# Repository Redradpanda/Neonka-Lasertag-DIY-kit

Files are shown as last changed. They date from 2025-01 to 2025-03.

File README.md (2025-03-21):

# Neonka-Lasertag-DIY-kit
Das ist ein Open Source Lasertag Projekt zum selber nachbauen.

lasertag front image

Alle notwendige Dateien und eine Anleitung sind in diesem Projekt gespeichert.

Dieses Hardware-Design ist lizenziert unter "CERN Open Hardware Licence Strongly Reciprocal, Version 2.0."
Den vollständigen Lizenztext finden Sie in der LICENSE-Datei.

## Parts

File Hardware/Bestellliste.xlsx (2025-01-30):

Bauteilkosten Lasertag
 | Pistole
 | Bauteil | Beschreibung | Link/Bestelladresse | CHF pro Stk. | Anzahl | CHF Total
 | Batteriehalter | 18650 Batteriehalter | https://de.aliexpress.com/item/1005006283753220.html | 1.03 | 1 | 1.03
 | Li-ion Batterien | 18650 Batterie (mit Schutzschaltung) |  | 9.9 | 1 | 9.9
 | ESP-32 | FireBeetle 2 ESP32-E |  | 12.9 | 1 | 12.9
 | Buzzer | 3V Piezo passiv Buzzer | https://www.mouser.ch/ProductDetail/Same-Sky/CMI-0955-03TH?qs=olJun0bQHM8qnyh30s0SwQ%3D%3D | 0.71 | 1 | 0.71
 | Sprungfeder | L2, R2 Steam Deck ersatzfeder | https://de.aliexpress.com/item/1005006748194855.html | 0.74 | 1 | 0.74
 | Linse | Bikonvex Linse (Google Cardboard), 25mm Brennweite 45mm fokalpunkt | https://de.aliexpress.com/item/1005006960995428.html | 0.29 | 1 | 0.29
 | Infrarot-LED | WP7113SF4BT-P22 | https://www.mouser.ch/ProductDetail/Kingbright/WP7113SF4BT-P22?qs=fAHHVMwC%252BbiHZc2nn9bMjA%3D%3D | 0.65 | 1 | 0.65
 | Kondensator | 100nF THT (ceramic) |  | 0.5 | 1 | 0.5
 | Widerstand | 47 Ohm THT |  | 0.01 | 1 | 0.01
 | Widerstand | 100 Ohm THT |  | 0.01 | 1 | 0.01
 | Widerstand | 10k Ohm THT |  | 0.01 | 2 | 0.02
 | Taster |  | https://de.aliexpress.com/item/1005004254514071.html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 | 0.05 | 1 | 0.05
 | Transistor | BS-170 THT |  | 0.05 | 1 | 0.05
 |  |  |  |  | Zwischentotal: | 26.86
 | Hit Detektor
 | Batteriehalter | 18650 Batteriehalter | https://de.aliexpress.com/item/1005006283753220.html | 1.03 | 1 | 1.03
 | Li-ion Batterien | 18650 Batterie (mit Schutzschaltung) |  | 9.9 | 1 | 9.9
 | ESP-32 | FireBeetle 2 ESP32-E |  | 12.9 | 1 | 12.9
 | Buzzer | 3V Piezo passiv Buzzer |  | 0.71 | 1 | 0.71
 | Infrarot-Reciever | TSOP-4138 | https://www.mouser.ch/ProductDetail/Vishay-Semiconductors/TSOP4138?qs=%2FCr5RXwmPBOIXjZmt6OK%2Fg%3D%3D | 0.6 | 6 | 3.6
 |  |  |  |  | Zwischentotal: | 28.14
 |  |  |  | Total: |  | 55

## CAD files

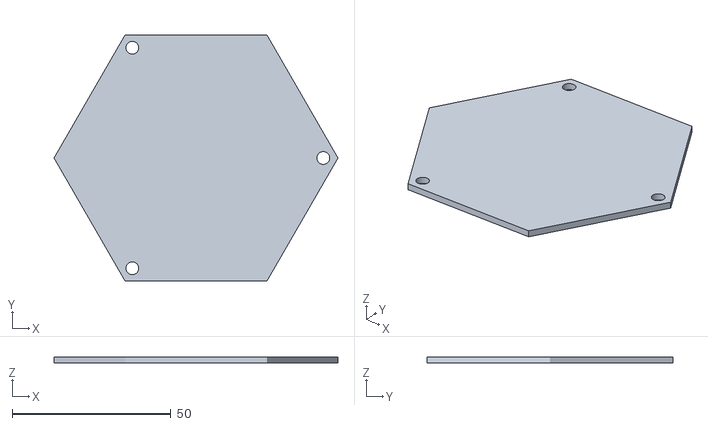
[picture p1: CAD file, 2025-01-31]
Mechanik/Hit Detektor/H-Deckel.stl
89.4 x 77.4 x 2.00

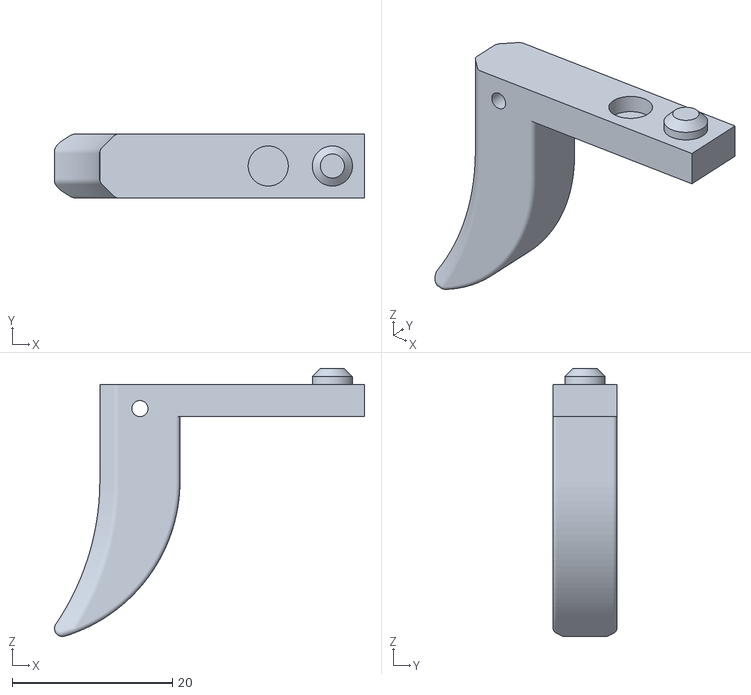
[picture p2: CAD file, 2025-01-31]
Mechanik/Pistole/P-Trigger.stl
38.7 x 8.00 x 33.4

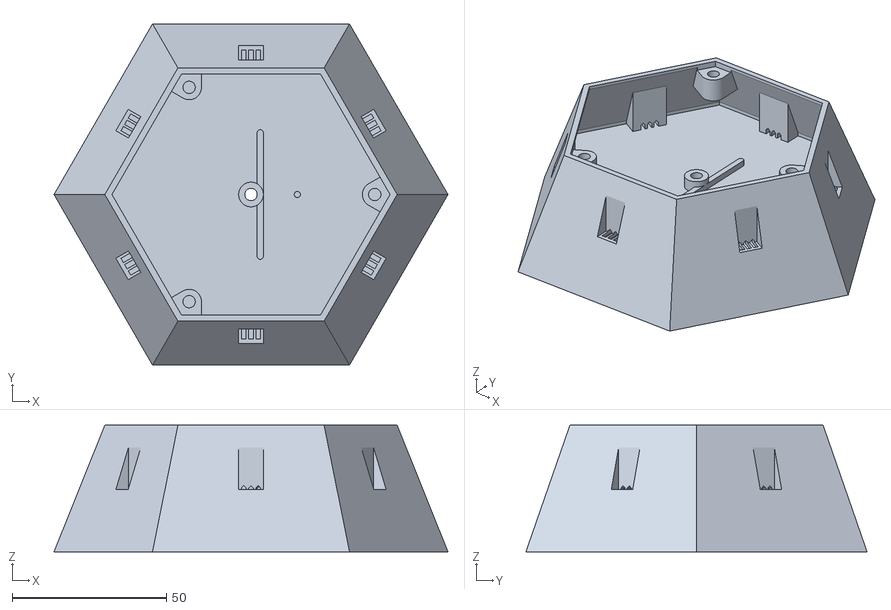
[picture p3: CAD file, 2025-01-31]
Mechanik/Hit Detektor/H-Gehäuse.stl
127.6 x 110.5 x 41.0

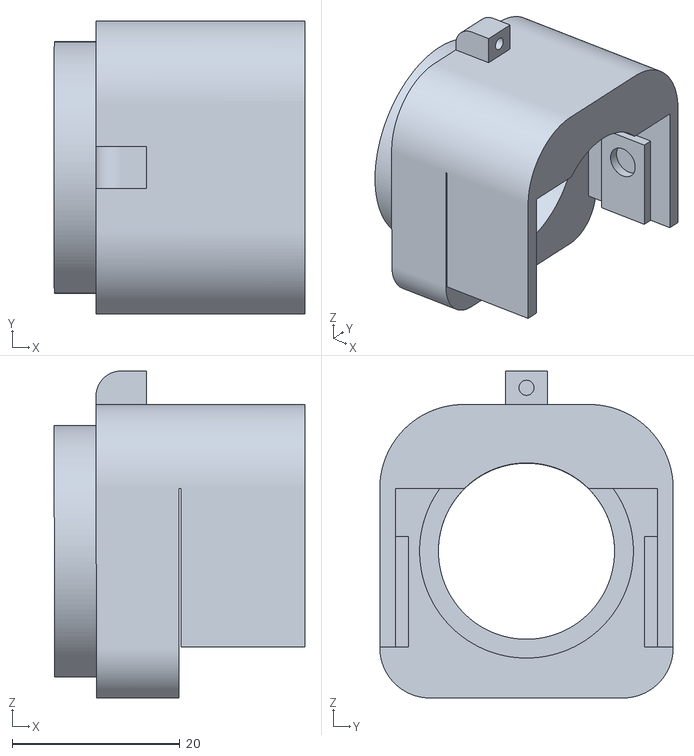
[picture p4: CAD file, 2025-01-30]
Mechanik/Pistole/P-Lauf-Mündung.stl
29.9 x 35.0 x 39.0

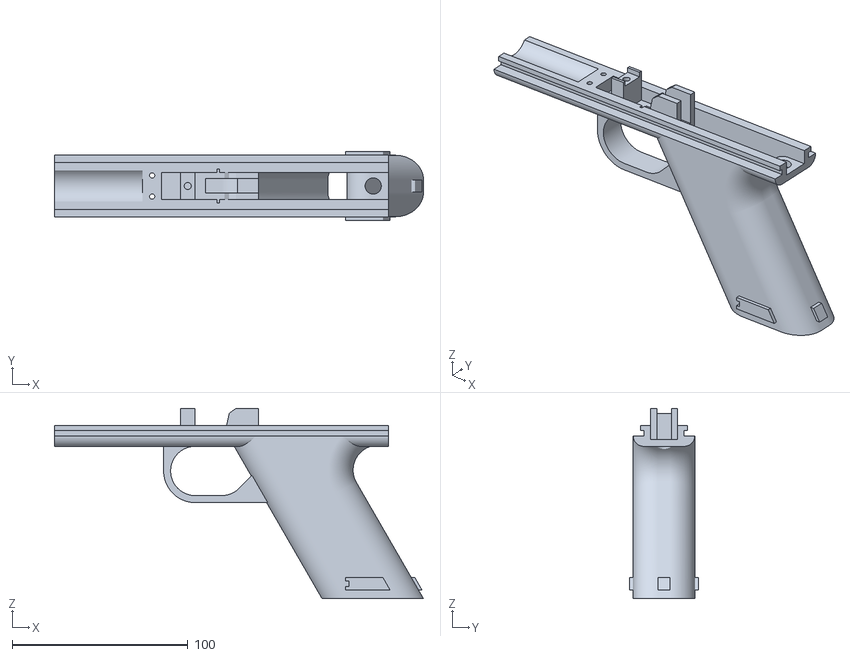
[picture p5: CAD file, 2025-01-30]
Mechanik/Pistole/P-Griff.stl
209.9 x 39.0 x 108.2

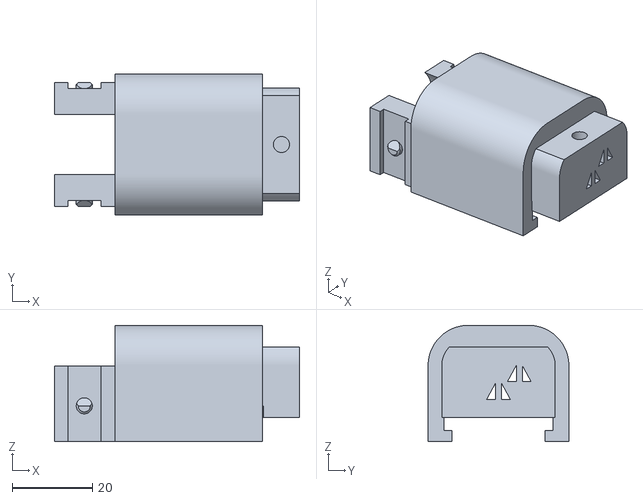
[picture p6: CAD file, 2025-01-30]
Mechanik/Pistole/P-Lauf-IR.stl
60.9 x 35.0 x 28.9

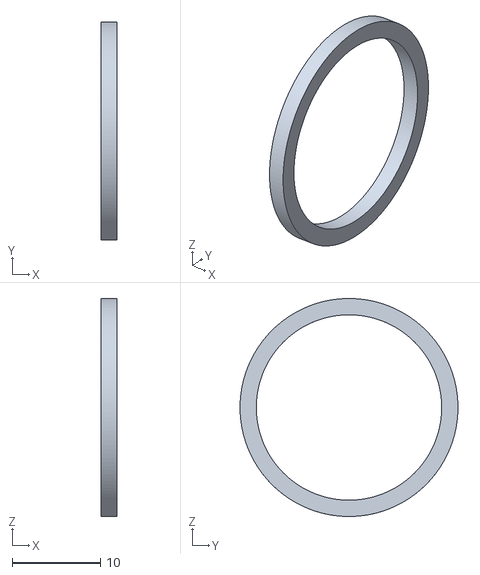
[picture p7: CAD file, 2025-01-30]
Mechanik/Pistole/P-Linse-Halter.stl
1.84 x 24.7 x 24.7

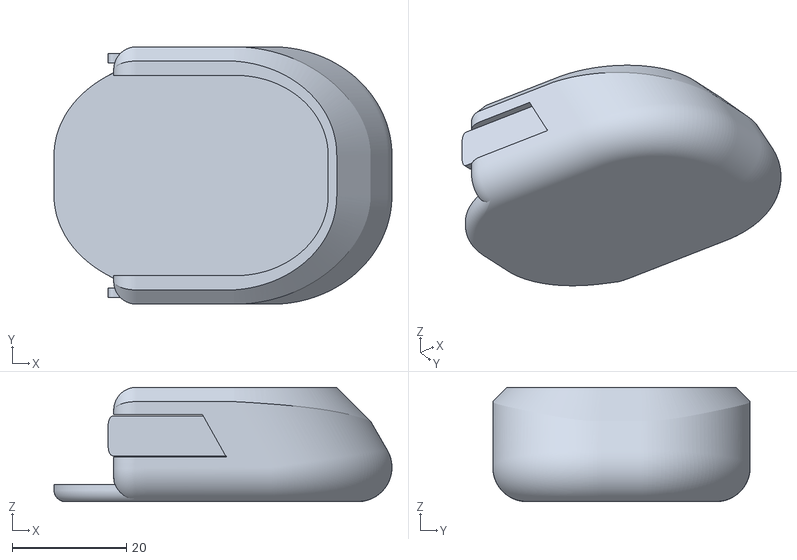
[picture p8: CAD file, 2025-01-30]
Mechanik/Pistole/P-Batterie-deckel.stl
59.1 x 45.0 x 20.0

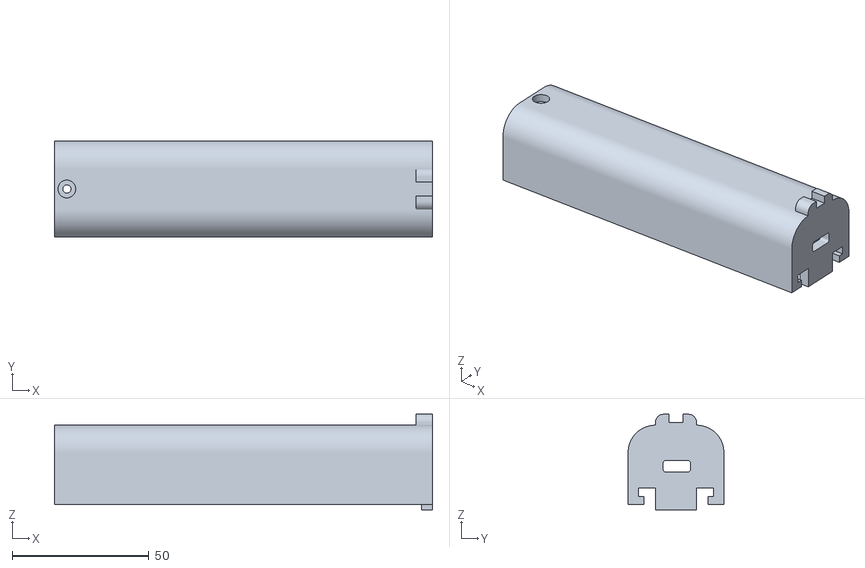
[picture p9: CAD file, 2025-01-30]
Mechanik/Pistole/P-Lauf-oben.stl
138.0 x 35.0 x 34.9

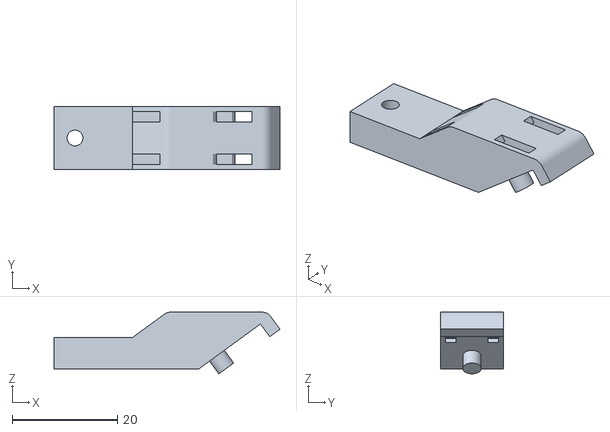
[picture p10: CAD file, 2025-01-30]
Mechanik/Pistole/P-Knopfhalter.stl
43.0 x 12.0 x 11.8

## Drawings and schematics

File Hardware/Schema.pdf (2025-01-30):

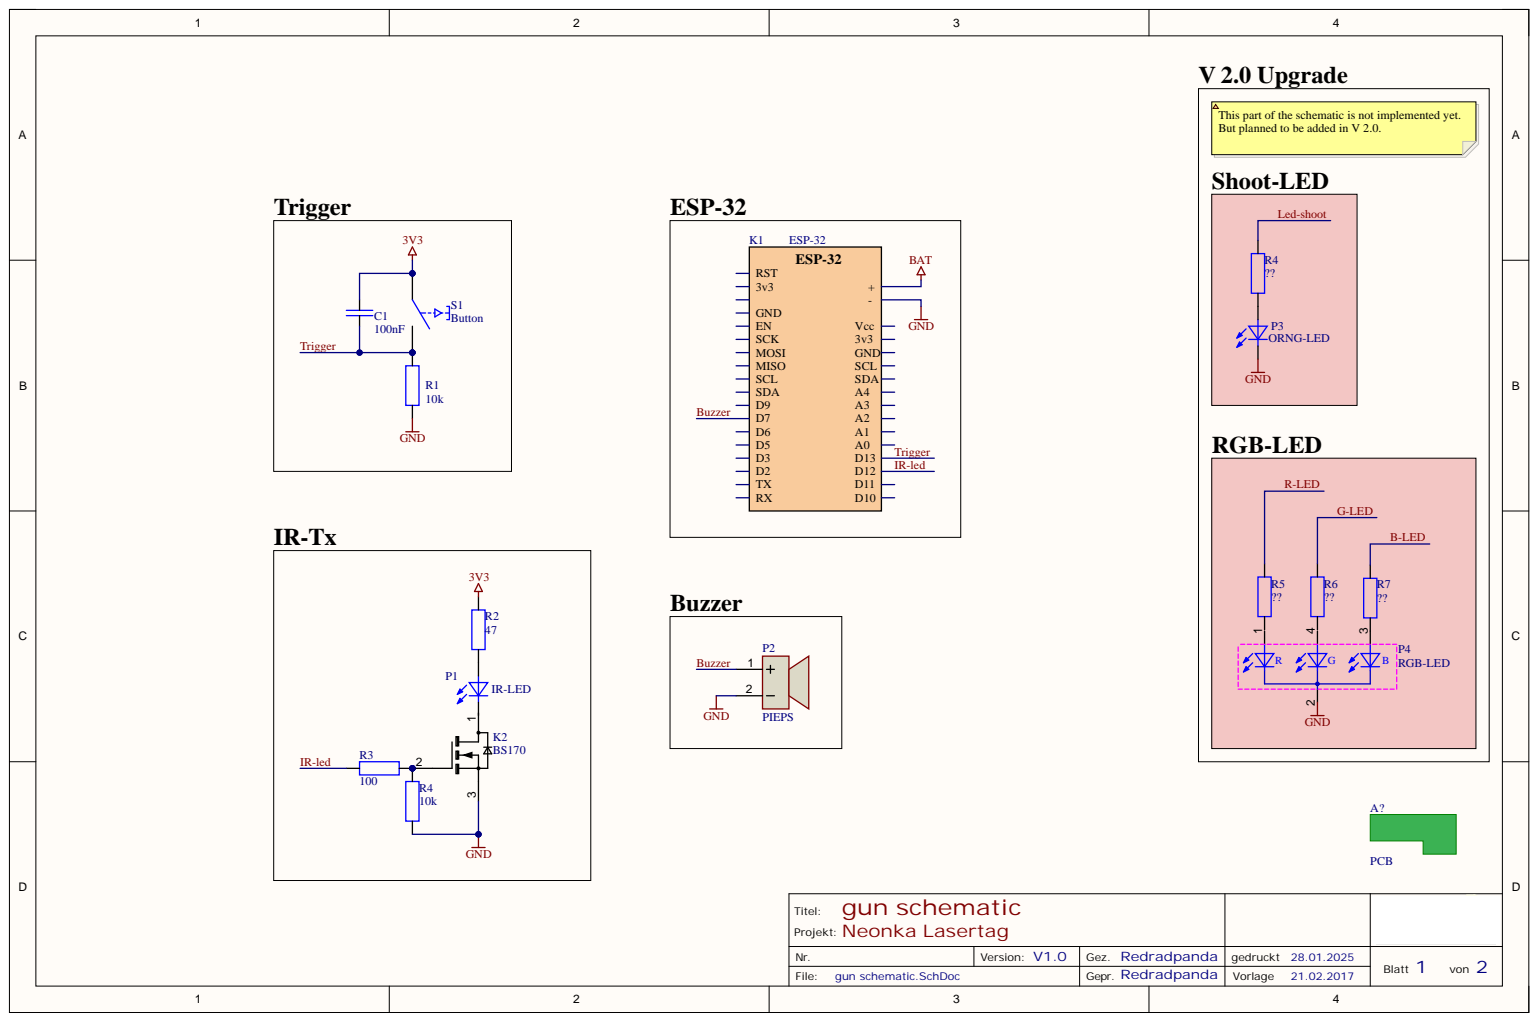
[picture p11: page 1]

This part of the schematic is not implemented yet.
But planned to be added in V 2.0.

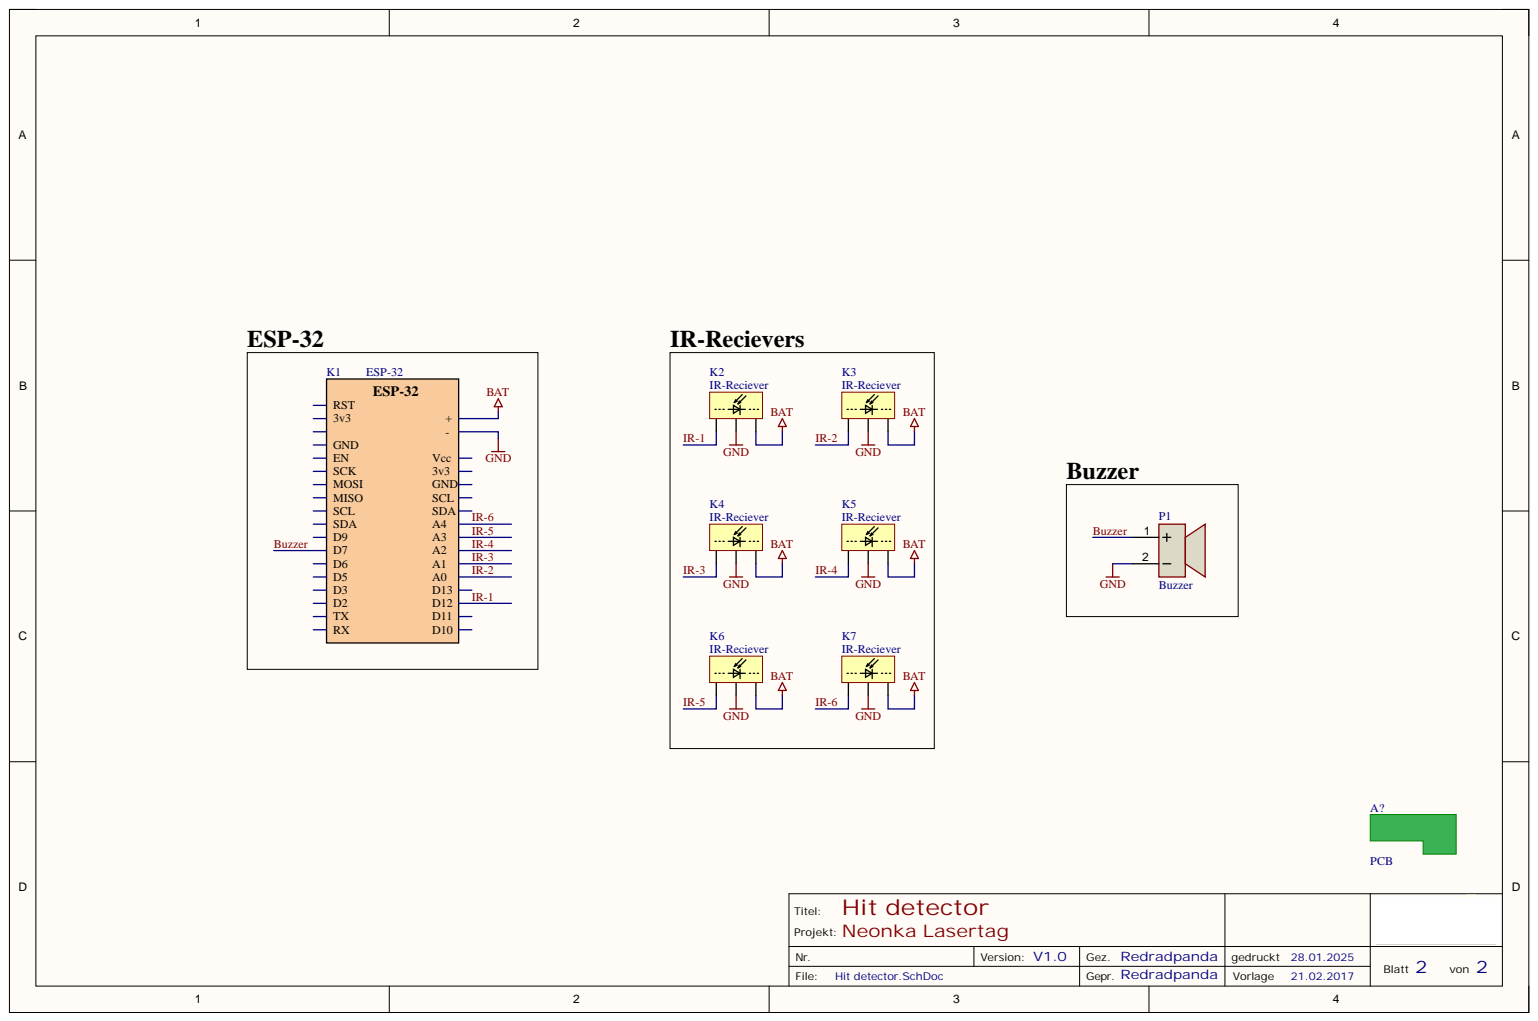
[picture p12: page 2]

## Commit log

2025-01-30 Added all files
    [Battery cap V.3.1 - Bat.-cover.stl, Bestellliste.xlsx, Part Studio V.3.1 - Barrel-top.stl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]
2025-01-31 Uploaded correct files
    [H-Deckel.stl, H-Gehäuse.stl, P-Batterie-deckel.stl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]
2025-01-31 Upladed files
    [H-Deckel.stl, H-Gehäuse.stl, P-Batterie-deckel.stl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]
